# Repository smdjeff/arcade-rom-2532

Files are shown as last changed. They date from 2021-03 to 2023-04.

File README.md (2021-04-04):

# Vintage 2532 arcade ROM programmer for Raspberry Pi

* Most ROM programmers that support vintage ROMs require old PC hardware and interfaces like ISA, LPT ports that are no longer readily available.
* USB based programmers like the TL866 don't support the high voltages, long programming cycles and high currents required of vintage EEPROMs.

* Convenient Raspberry Pi Hat style form factor.
* Uses an eight bit shift register as both an IO expander and 5V level shifter to interface ROM address lines. 
* A real bi-directional level shifter for the ROM's data pins.
* An analog mux supporting the ROM's full high voltages and current.
* Simple C driver program used directly on the Pi's command line.
* [Smart single-byte retry algorithm](https://www.youtube.com/watch?v=HBokTF31uQM) accounts for difficult to program adddresses and lower VPP voltages.
* Supports several vintage classic arcade machine ROMs - like those in Space Invaders, Donkey Kong and Pacman.

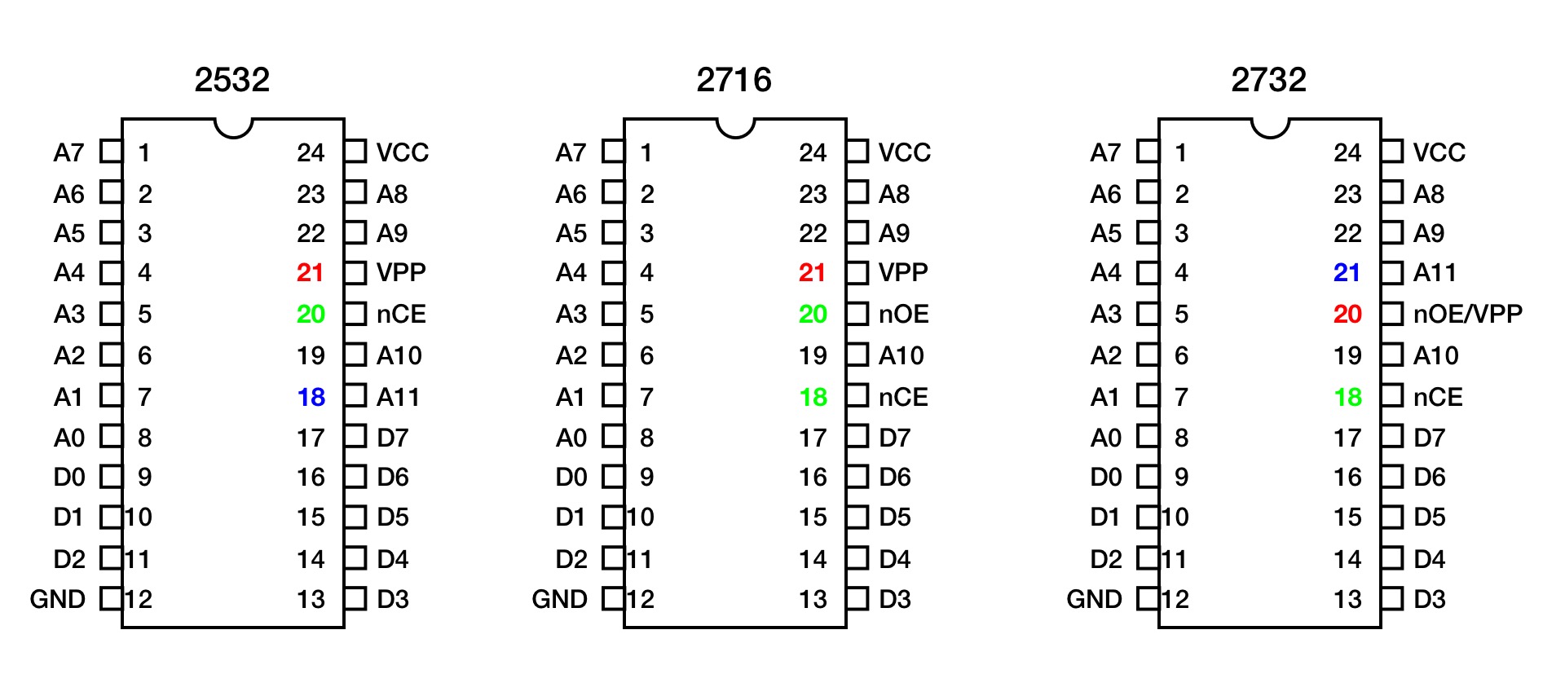
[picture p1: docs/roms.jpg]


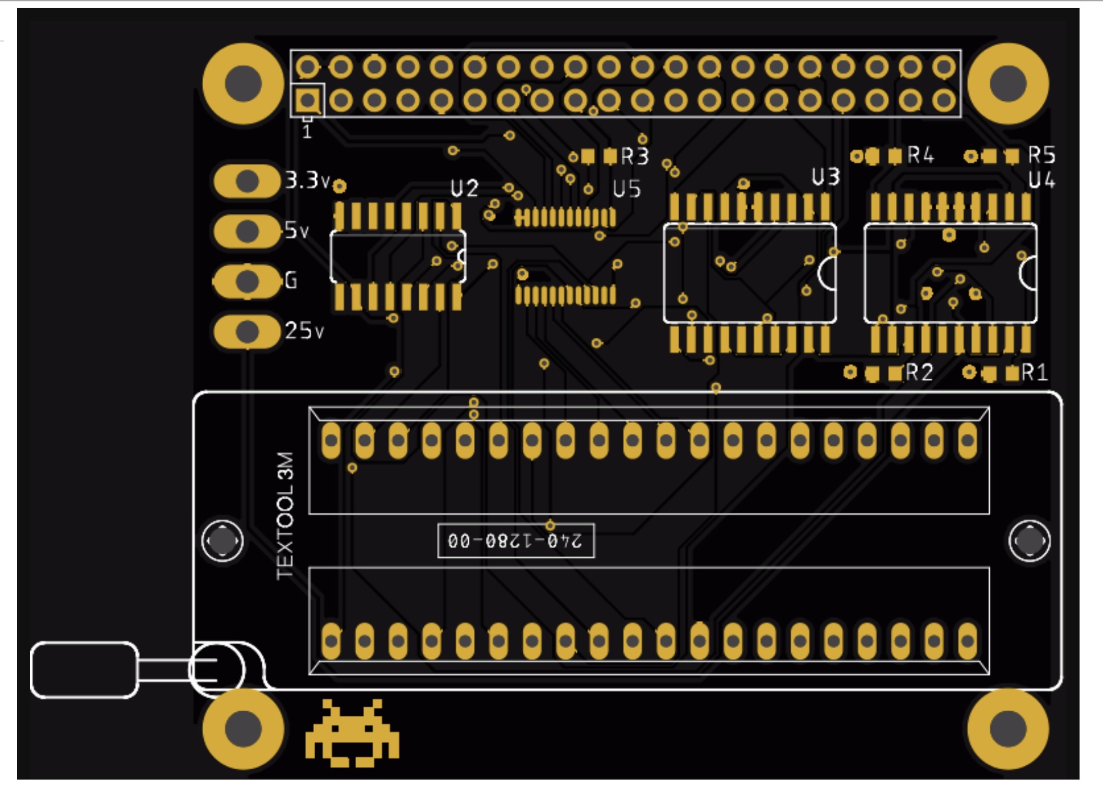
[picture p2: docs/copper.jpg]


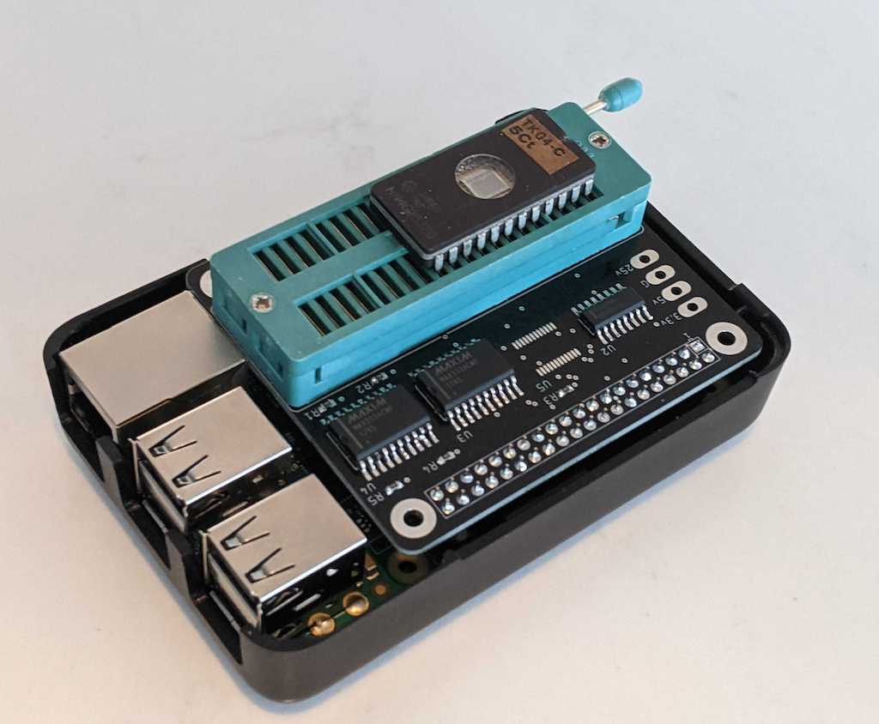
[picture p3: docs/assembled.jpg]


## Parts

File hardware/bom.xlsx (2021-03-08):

Designator | Manufacturer Part Number or Seeed SKU | Qty | Link
U1,U2 | MC74HCT595ADG | 2 | https://www.digikey.com/product-detail/en/MC74HCT595ADG/MC74HCT595ADGOS-ND/2748311/?itemSeq=357039637
U5 | SN74LVCC3245ADW | 1 | https://www.digikey.com/product-detail/en/SN74LVCC3245ADW/296-1704-5-ND/277350/?itemSeq=357039815
U3,U4 | MAX333ACWP+ | 2 | https://www.digikey.com/product-detail/en/MAX333ACWP%2b/MAX333ACWP%2b-ND/947930/?itemSeq=357039873
X2 | 2222 | 1 | https://www.digikey.com/product-detail/en/2222/1528-1785-ND/6238005/?itemSeq=357040007
R1,R2,R3,R4,R5 | CR0603-JW-103ELF | 5 | https://www.digikey.com/product-detail/en/CR0603-JW-103ELF/CR0603-JW-103ELFCT-ND/3592890/?itemSeq=357040105

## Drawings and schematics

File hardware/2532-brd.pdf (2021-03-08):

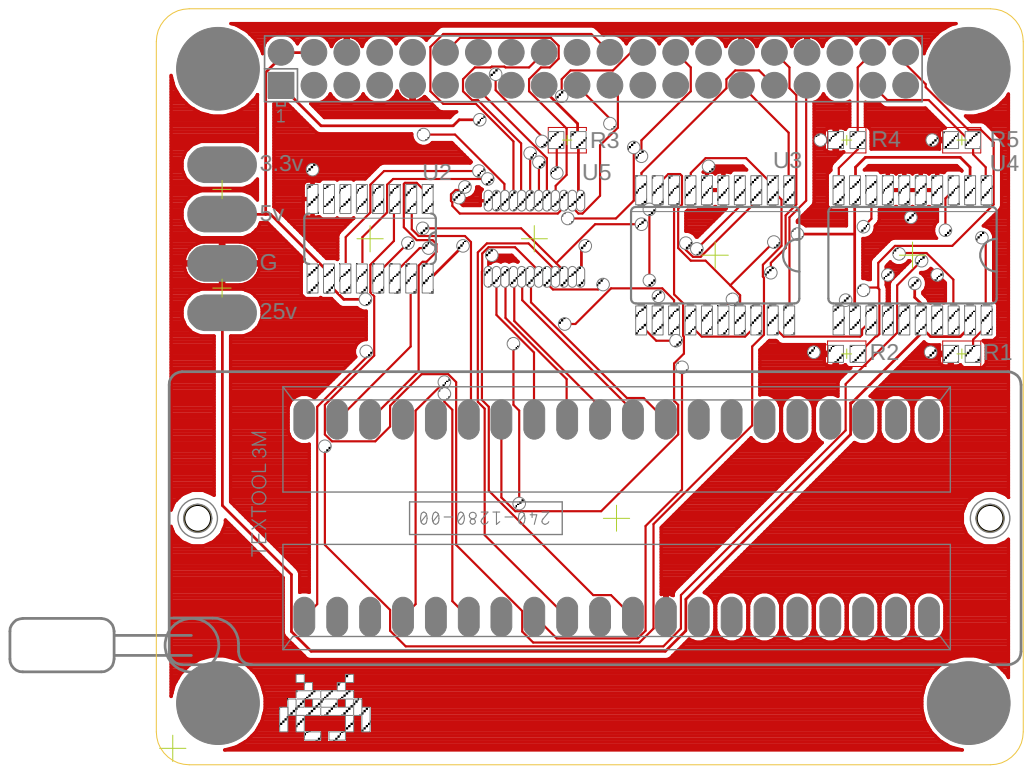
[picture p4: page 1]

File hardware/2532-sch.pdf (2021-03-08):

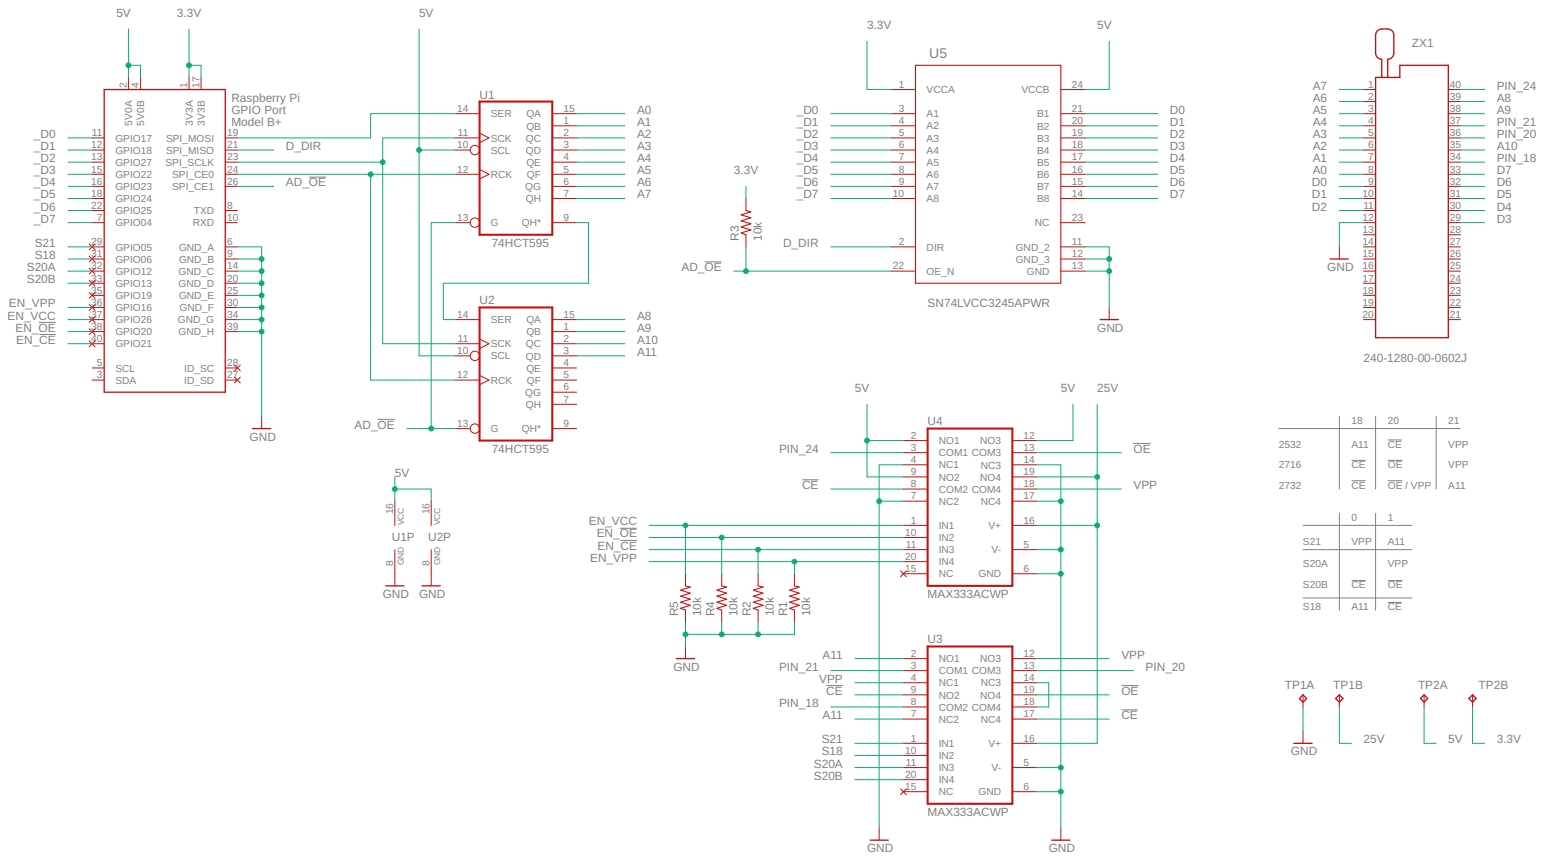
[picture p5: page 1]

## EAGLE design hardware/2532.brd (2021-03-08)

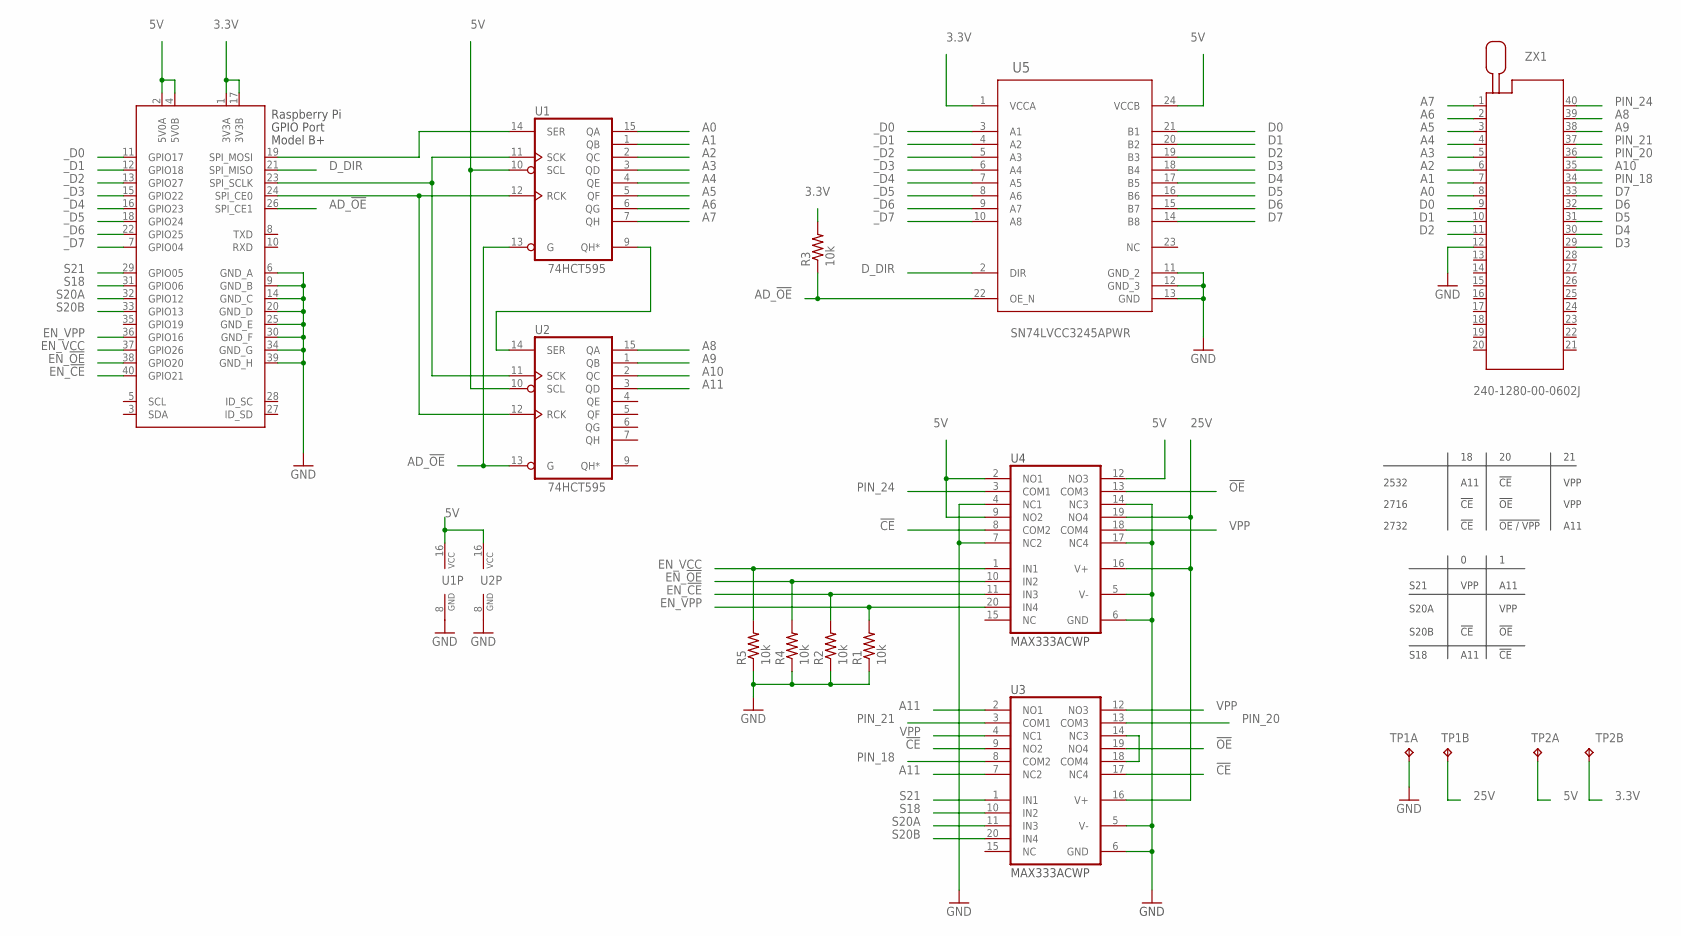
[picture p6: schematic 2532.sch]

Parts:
R1, R2, R3, R4, R5: 10k; R0603
TP1, TP2: TP2P2-38-17; P2-38-17
U1, U2: 74HCT595; SO16
U3, U4: MAX333ACWP; SO20L
U5: Value; PW0024A_N
X2: RASPI_BOARD_B+#_E4P; RASPI_BOARD_B+_EDGES_4DRILL_PAD
ZX1: 240-1280-00-0602J

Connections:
3.3V: R3.2, TP2.TP-2, U5.1 (VCCA), X2.1 (3V3A), X2.17 (3V3B)
5V: TP2.TP-1, U1.10 (SCL), U1.16 (VCC), U2.10 (SCL), U2.16 (VCC), U4.2 (NO1), U4.9 (NO2), U4.12 (NO3), U5.24 (VCCB), X2.2 (5V0A), X2.4 (5V0B)
25V: TP1.TP-2, U3.16 (V+), U4.16 (V+), U4.19 (NO4)
!CE: U3.9 (NO2), U3.17 (NC4), U4.8 (COM2)
!OE: U3.19 (NO4), U4.13 (COM3)
A0: U1.15 (QA), ZX1.8
A1: U1.1 (QB), ZX1.7
A2: U1.2 (QC), ZX1.6
A3: U1.3 (QD), ZX1.5
A4: U1.4 (QE), ZX1.4
A5: U1.5 (QF), ZX1.3
A6: U1.6 (QG), ZX1.2
A7: U1.7 (QH), ZX1.1
A8: U2.15 (QA), ZX1.39
A9: U2.1 (QB), ZX1.38
A10: U2.2 (QC), ZX1.35
A11: U2.3 (QD), U3.2 (NO1), U3.7 (NC2)
AD_!OE: R3.1, U1.13 (G), U2.13 (G), U5.22 (OE_N), X2.26 (SPI_CE1)
D0: U5.21 (B1), ZX1.9
D1: U5.20 (B2), ZX1.10
D2: U5.19 (B3), ZX1.11
D3: U5.18 (B4), ZX1.29
D4: U5.17 (B5), ZX1.30
D5: U5.16 (B6), ZX1.31
D6: U5.15 (B7), ZX1.32
D7: U5.14 (B8), ZX1.33
D_DIR: U5.2 (DIR), X2.21 (SPI_MISO)
EN_!CE: R2.2, U4.11 (IN3), X2.40 (GPIO21)
EN_!OE: R4.2, U4.10 (IN2), X2.38 (GPIO20)
EN_VCC: R5.2, U4.1 (IN1), X2.37 (GPIO26)
EN_VPP: R1.2, U4.20 (IN4), X2.36 (GPIO16)
GND: R1.1, R2.1, R4.1, R5.1, TP1.TP-1, U1.8 (GND), U2.8 (GND), U3.5 (V-), U3.6 (GND), U4.4 (NC1), U4.5 (V-), U4.6 (GND), U4.7 (NC2), U4.14 (NC3), U4.17 (NC4), U5.11 (GND_2), U5.12 (GND_3), U5.13 (GND), X2.6 (GND_A), X2.9 (GND_B), X2.14 (GND_C), X2.20 (GND_D), X2.25 (GND_E), X2.30 (GND_F), X2.34 (GND_G), X2.39 (GND_H), ZX1.12
unnamed: U3.14 (NC3), U3.18 (COM4)
unnamed: U1.11 (SCK), U2.11 (SCK), X2.23 (SPI_SCLK)
unnamed: U1.12 (RCK), U2.12 (RCK), X2.24 (SPI_CE0)
unnamed: U1.9 (QH*), U2.14 (SER)
unnamed: U1.14 (SER), X2.19 (SPI_MOSI)
PIN_18: U3.8 (COM2), ZX1.34
PIN_20: U3.13 (COM3), ZX1.36
PIN_21: U3.3 (COM1), ZX1.37
PIN_24: U4.3 (COM1), ZX1.40
S18: U3.10 (IN2), X2.31 (GPIO06)
S20A: U3.11 (IN3), X2.32 (GPIO12)
S20B: U3.20 (IN4), X2.33 (GPIO13)
S21: U3.1 (IN1), X2.29 (GPIO05)
VPP: U3.4 (NC1), U3.12 (NO3), U4.18 (COM4)
_D0: U5.3 (A1), X2.11 (GPIO17)
_D1: U5.4 (A2), X2.12 (GPIO18)
_D2: U5.5 (A3), X2.13 (GPIO27)
_D3: U5.6 (A4), X2.15 (GPIO22)
_D4: U5.7 (A5), X2.16 (GPIO23)
_D5: U5.8 (A6), X2.18 (GPIO24)
_D6: U5.9 (A7), X2.22 (GPIO25)
_D7: U5.10 (A8), X2.7 (GPIO04)

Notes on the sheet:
S21 S20A S20B S18
VPP !CE A11
A11 VPP !OE !CE
2532 2716 2732
!CE !OE !OE / VPP
VPP VPP A11
A11 !CE !CE

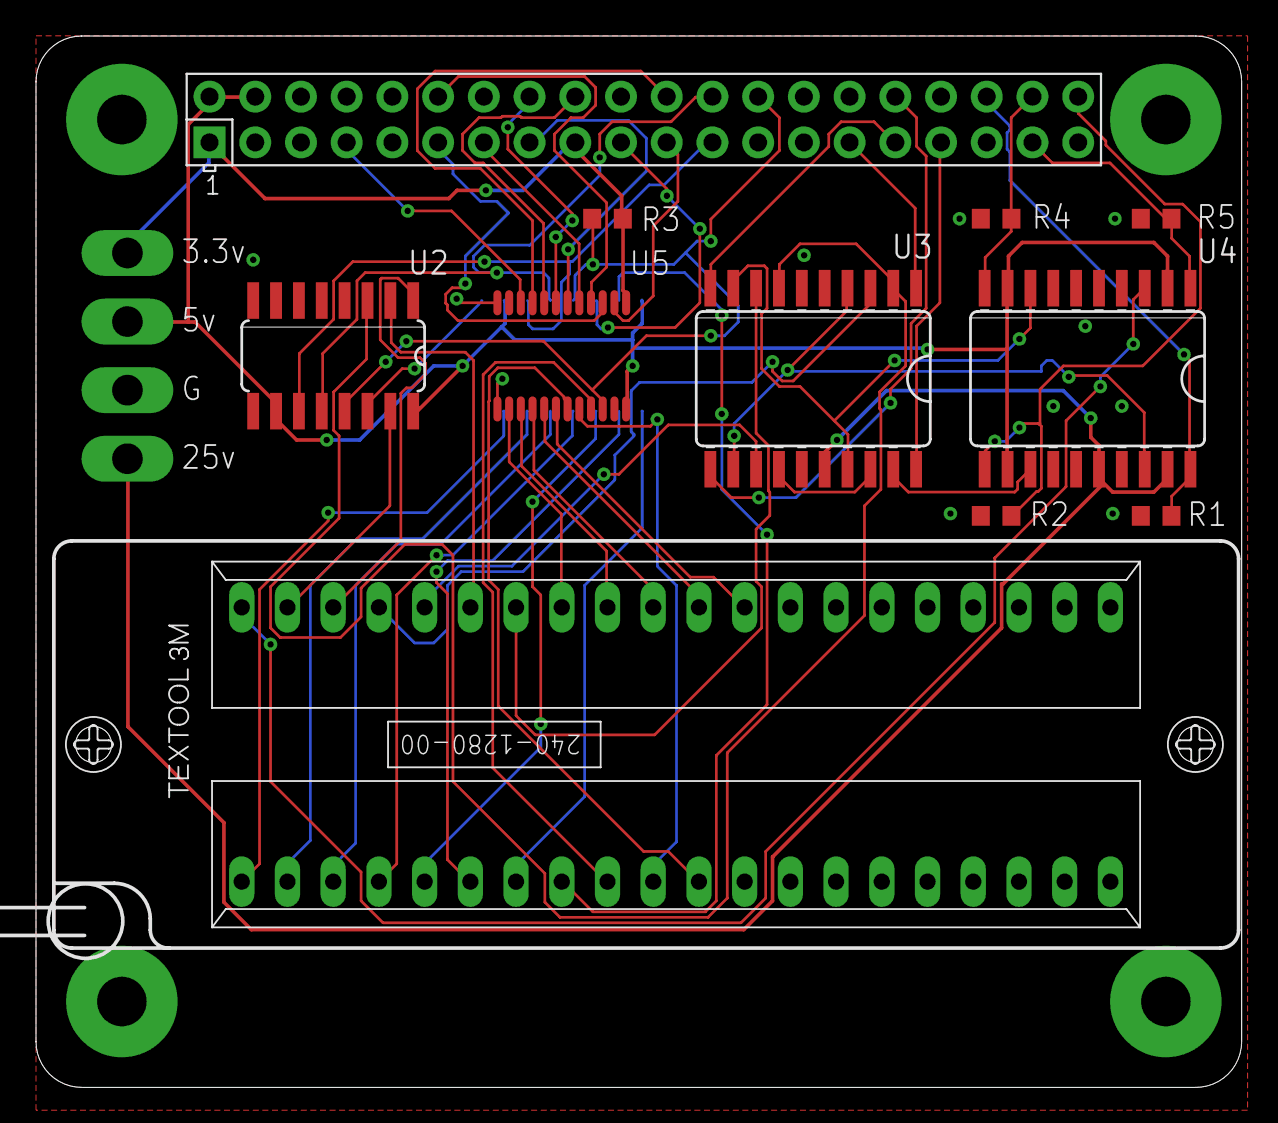
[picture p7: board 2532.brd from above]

Board: 2 copper layers, 67.0 x 58.4 mm, 14 parts (1 on the bottom side), 54 nets.

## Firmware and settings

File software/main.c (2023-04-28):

#define _GNU_SOURCE
#include <stdlib.h>
#include <stdint.h>
#include <stdbool.h>
#include <stdio.h>
#include <string.h>
#include <signal.h>
#include <sys/time.h>
#include <assert.h>
#include <unistd.h>

#include "portable.h"
#include "getchar_nonblock.h"

    
#define DELAY_US(us) do{ usleep(us); } while(0)    
#define DELAY_MS(ms) do{ usleep(ms*1000L); } while(0)

// note: do not connect 3.3V it is supplied via the Raspberry Pi
//       do not connect 5V it is supplied via Raspberry Pi's USB wallwart
//       VPP is supplied via external power supply
//       19-25vdc VPP for programming while higher voltages req fewer retries
//       at least 5.2vdc should be supplied to VPP during read/verify 
#define _5V         0
#define _25V        1

#define OFF         0
#define ON          1
#define LOW         0
#define HIGH        1

// hack: unfortunately the MAX333 analog switch is only good
// for up to 30mA and these older EPROMs need 160mA + on VCC
// so a PNP BJT is bluewired and that's inverting VCC logic  
#define VCC(v)      do { gpioWrite( EN_VCC, !v ); } while(0)

#define VPP(v)      do { gpioWrite( EN_VPP, v ); } while(0)
#define NCE(v)      do { gpioWrite( EN_NCE, v ); } while(0)
#define NPGM(v)     do { gpioWrite( EN_NCE, v ); } while(0)
#define NOE(v)      do { gpioWrite( EN_NOE, v ); } while(0)


typedef enum {
    rom2532,
    rom2716,
    rom2732
} romType_t;


static void romSelect(romType_t romType) {
    switch (romType) {
        case rom2532:
            printf("2532 selected\n");
            // all pins check out
            gpioWrite( IO_S18,  0 ); // pin 18  [0:A11] 1:nCE
            gpioWrite( IO_S20A, 0 ); // pin 20  [0:20B] 1:VPP
            gpioWrite( IO_S20B, 0 ); //         [0:nCE] 1:nOE
            gpioWrite( IO_S21,  0 ); // pin 21  [0:VPP] 1:A11
            break;
        case rom2716:
            printf("2716 selected\n");
            gpioWrite( IO_S18,  1 ); // pin 18  0:A11 [1:nCE]
            gpioWrite( IO_S20A, 0 ); // pin 20  [0:20B] 1:VPP
            gpioWrite( IO_S20B, 1 ); //         0:nCE [1:nOE]
            gpioWrite( IO_S21,  0 ); // pin 21  [0:VPP] 1:A11
            break;
        case rom2732:
            printf("2732 selected\n");
            printf("warning: support for this chip is incomplete\n"); getchar();
            // A11 bad, & nCE/nOE issue?
            gpioWrite( IO_S18,  1 ); // pin 18  0:A11 [1:nCE]
            gpioWrite( IO_S20A, 1 ); // pin 20  0:20B [1:VPP]
            gpioWrite( IO_S20B, 1 ); //         0:nCE [1:nOE]
            gpioWrite( IO_S21,  1 ); // pin 21  0:VPP [1:A11]
            break;
        default:
            assert(false);
            break;
    }
}


static void dataPinsMode(int mode) {
    uint8_t pins[] = { 
        IO_D0, IO_D1, IO_D2, IO_D3, IO_D4, IO_D5, IO_D6, IO_D7
    };
    for (int i=0; i<sizeof(pins); i++) {
        gpioWrite( pins[i], 0 );
        gpioSetMode( pins[i], mode );
    }
    // SN74LVCC3245 mode
    if ( mode == PI_OUTPUT ) {        
        gpioWrite( D_DIR, 1 ); // A data to B bus
    } else {
        gpioWrite( D_DIR, 0 ); // B data to A bus
    }
}


static void controlPinsMode(int mode) {
    typedef struct {
        int gpio;
        int value;
    } pins_t;
    pins_t pins[] = { 
        {IO_S21,0}, {IO_S18,0}, {IO_S20A,0}, {IO_S20B,0},
        {EN_VPP,0}, {EN_VCC,0}, {EN_NOE,1}, {EN_NCE,1},
        {D_DIR,0}, {AD_NOE,0},
        {SPI_CE0,1}, {SPI_MOSI,0}, {SPI_CLK,0}
    };
    for (int i=0; i<sizeof(pins)/sizeof(pins[0]); i++) {
        printf("gpio %d value:%d mode:%d\n", pins[i].gpio, pins[i].value, mode );
        gpioWrite( pins[i].gpio, pins[i].value );
        gpioSetMode( pins[i].gpio, mode );
    }
}


static void writeAddress(uint16_t addr) {
    // put the address out on the MC74HCT595
    gpioWrite( SPI_CE0, 0 );
    for (int i=15; i>=0; i--) {  // msb
        gpioWrite( SPI_CLK, 0 );
        DELAY_US(1);
        gpioWrite( SPI_MOSI, (addr & (1<<i) ? 1:0) );
        DELAY_US(1);
        gpioWrite( SPI_CLK, 1 ); // shift bit in
        DELAY_US(1);
    }
    gpioWrite( SPI_CE0, 1 );  // latch 595
    gpioWrite( SPI_CLK, 0 );
    gpioWrite( SPI_MOSI, 0 );
}


static void writeByte(uint8_t b) {
    // put the data out on the SN74LVCC3245
    dataPinsMode( PI_OUTPUT );
    gpioWrite( IO_D0, (b & 0b00000001)?1:0 );
    gpioWrite( IO_D1, (b & 0b00000010)?1:0 );
    gpioWrite( IO_D2, (b & 0b00000100)?1:0 );
    gpioWrite( IO_D3, (b & 0b00001000)?1:0 );
    gpioWrite( IO_D4, (b & 0b00010000)?1:0 );
    gpioWrite( IO_D5, (b & 0b00100000)?1:0 );
    gpioWrite( IO_D6, (b & 0b01000000)?1:0 );
    gpioWrite( IO_D7, (b & 0b10000000)?1:0 );
}


static void readByte(uint8_t *b) {
    // read data in from the SN74LVCC3245
    dataPinsMode( PI_INPUT );
    *b =  gpioRead( IO_D0 );
    *b |= gpioRead( IO_D1 ) << 1;
    *b |= gpioRead( IO_D2 ) << 2;
    *b |= gpioRead( IO_D3 ) << 3;
    *b |= gpioRead( IO_D4 ) << 4;
    *b |= gpioRead( IO_D5 ) << 5;
    *b |= gpioRead( IO_D6 ) << 6;
    *b |= gpioRead( IO_D7 ) << 7;
}


// Intel 2716
static void write2716(uint8_t *data, int sz) {
    // VPP always at +25V
    // for each byte, Pull \OE high, delay 1 usec
    // assert address, assert data, delay 2 usec
    // pulse \CE high for 55msec
    // set data as inputs
    // pull \OE low, wait 1usec
    // verify correct data being asserted by target.

    NCE( LOW );
    NOE( LOW );
    VPP( _25V );
    DELAY_US( 2 );

    for (int i=0; i<sz; i++ ) {
      uint8_t w = data[i];
      uint8_t r = 0xff;

      for (int j=0; j<10; j++ ) {

        NOE( HIGH );
        DELAY_US( 1 );

        writeAddress( i );
        writeByte( w );
        DELAY_US( 2 );

        NCE( HIGH );
        DELAY_MS( 55 );
        NCE( LOW );

        dataPinsMode( PI_INPUT );

        DELAY_US( 2 );
        NOE( LOW );
        DELAY_US( 1 );

        readByte( &r );
        if ( r == w ) {
           break;
        } else {
           printf("RETRY addr:%04x wrote:%02x read:%02x\n",i, w, r );
   	   DELAY_MS( 250 );
        }
      }

      printf("%saddr:%04x wrote:%02x read:%02x\n",(r==w)?"":"*FAIL* ",i, w, r );
    }

    VPP( _5V );
}

static void write2732(uint8_t *data, int sz) {
/*
2732 is: Start with \CE high, \OE low.  Raise \OE to VPP, delay 1usec, assert address, assert data, delay 2 usec, pulse \CE low for 55msec, delay 2 usec, pull \OE low, delay 2 usec, pull \CE low, delay 1 usec, verify correct data being asserted by target.
*/
    
    NCE( HIGH );
    NOE( LOW );

    VPP( _25V );
    DELAY_US( 1 );
    
    for (int i=0; i<sz; i++ ) {
        // //*** OE/CE?
        uint8_t w = data[i];
        writeAddress( i );
        writeByte( w );
        DELAY_US( 2 );

        NCE( LOW );  //*** opposite of 2716?
        DELAY_MS( 55 );
        NCE( HIGH );  //***
        DELAY_US( 2 );
        
        NOE( LOW ); 
        DELAY_US( 2 );
        NCE( LOW ); 
        DELAY_US( 1 );
        
        uint8_t r = 0xff;
        readByte( &r );
        if ( r != w ) {
            printf("FAIL ");
        }
        printf("addr:%04x wrote:%02x read:%02x\n", i, w, r );
    }
    
    VPP( _5V );
}


// Texas Instruments TMS2532
static void writeTMS2532(uint8_t *data, int sz) {
/*
-With \PGM high, assert address
-Raise Vpp from VCC to +25V
-Assert data
-Wait at least 2 microseconds
-Pulse \PGM low for 55 milliseconds
*/
    NPGM( HIGH );
    DELAY_US( 2 );

    for (int i=0; i<sz; i++ ) {
        uint8_t w = data[i];

        writeAddress( i );
        
        VPP( _25V );
        DELAY_US( 2 );

        writeByte( w );
        DELAY_US( 2 );

        NPGM( LOW ); 
        DELAY_MS( 55 );
        NPGM( HIGH );
        DELAY_US( 2 );
        
        VPP( _5V );
        
        uint8_t r = 0xff;
        readByte( &r );
        if ( r != w ) {
            printf("FAIL ");
        }
        printf("addr:%04x wrote:%02x read:%02x\n", i, w, r );
    }
}

// Hitachi HD462532
static void writeHD2532(uint8_t *data, int sz) {
    // Start with \CE high
    // raise VPP to +25V
    // assert address
    // assert data
    // delay 2usec
    // pulse \CE low for 55msec
    // delay 2usec
    // lower VPP to +5V, 
    // delay 2usec
    // pull \CE low
    // verify correct data being asserted by target
    
    for (int i=0; i<sz; i++ ) {
      uint8_t w = data[i];
      uint8_t r = 0xff;
      
      for (int j=0; j<10; j++ ) {

        NCE( LOW ); 
        writeAddress( i );
//        readByte( &r );
//        if ( r == w ) { break; } 

        NCE( HIGH );
        VPP( _25V );

        writeByte( w );
        DELAY_US( 2 );
        
        NCE( LOW ); 
        DELAY_MS( 55 );
        NCE( HIGH ); 
        DELAY_US( 2 );

        VPP( _5V );
        DELAY_US( 2 );
        
        NCE( LOW );  
        DELAY_US( 1 );
        
        readByte( &r );
        if ( r == w ) {
           break;
        } else {
           fprintf(stderr,"RETRY addr:%04x wrote:%02x read:%02x\n",i, w, r );
   	   DELAY_MS( 1000 );
        }
      }
      printf("%saddr:%04x wrote:%02x read:%02x\n",(r==w)?"":"*FAIL* ",i, w, r );
    } 
}


static void romRead(uint8_t *data, int sz) {
    dataPinsMode( PI_INPUT );
    
    NOE( LOW );
    NCE( LOW );

    for (int i=0; i<sz; i++ ) {
        writeAddress( i );
        readByte( &data[i] );
    }
}


int main(int argc, char *argv[]) {

    if (argc < 4) {
       printf("Usage:\n romhat [TMS2532|HD2532|2716|2732] -w|r|v|b file\n");
       exit(1);
    }
    char *type = argv[1];
    char *mode = argv[2];
    char *filename = argv[3];

    assert( gpioInitialise() >= 0 );
    controlPinsMode( PI_OUTPUT );
    dataPinsMode( PI_INPUT );
    gpioWrite( AD_NOE,  0 ); // enables outputs of 595 and 245
    
    printf("VCC ON\n"); 
    VCC( ON );

    int romSize = 0;
    void (*romWrite)(uint8_t *data, int sz) = NULL;

    if ( strcasestr( type, "HD2532" ) ) {
        romSize = 32 *1024/8;            
        romSelect( rom2532 );
        romWrite = writeHD2532;
    }
    else if ( strcasestr( type, "TMS2532" ) ) {
        romSize = 32 *1024/8;            
        romSelect( rom2532 );
        romWrite = writeTMS2532;
    }
    else if ( strcasestr( type, "2716" ) ) {
        romSize = 16 *1024/8;            
        romSelect( rom2716 );
        romWrite = write2716;
    }
    else if ( strcasestr( type, "2732" ) ) {
        romSize = 32 *1024/8;            
        romSelect( rom2732 );
        romWrite = write2732;
    } 

    printf("rom type selection complete\n"); 

    if ( strcasestr( mode, "t" ) ) {
        printf("pin test\n"); getchar();

        int gpio[] = { 0,2,3,4,0,17,27,22,0,10,9,11,0,0,5,6,13,19,26,0 };
	for (int i=0; i<sizeof(gpio)/sizeof(gpio[0]); i++) {
           if ( gpio[i] == 0 ) {
              printf("pin:%d skip\n", 1+(i*2));
              continue;
           }
           printf("pin:%d gpio: %d\n", 1+(i*2), gpio[i]);
	   gpioSetMode( gpio[i], PI_OUTPUT );
           nonblocking( true );
           do {
              DELAY_MS( 500 );
              int v = !gpioRead( gpio[i] );
  	      gpioWrite( gpio[i], v );
           } while ( getchar_nonblock()==0 );
           nonblocking( false );
        }

	controlPinsMode( PI_OUTPUT ); getchar();
	controlPinsMode( PI_INPUT ); getchar();

	controlPinsMode( PI_OUTPUT );
        for (int i=0; i<12; i++) {
            writeAddress( 1<<i );
            printf("A%d HI\n",i); getchar();
        }

	dataPinsMode( PI_OUTPUT ); getchar();
	dataPinsMode( PI_INPUT ); getchar();

	dataPinsMode( PI_OUTPUT );
        for (int i=0; i<8; i++) {
            writeByte( 1<<i );
            printf("D%d HI\n",i); getchar();
        }
	dataPinsMode( PI_INPUT );

        printf("VPP ON\n"); VPP( ON ); getchar();
        printf("VPP OFF\n"); VPP( OFF );getchar();
    
        printf("NCE HIGH\n"); NCE( HIGH ); getchar();
        printf("NCE LOW\n"); NCE( LOW ); getchar();

        printf("NOE HIGH\n"); NOE( HIGH ); getchar();
        printf("NOE LOW\n"); NOE( LOW ); getchar();
    }

    if ( strcasestr( mode, "w" ) ) {
        printf("write\n");

        if( access( filename, F_OK ) == 0 ) {
            char *data = malloc( romSize );
            assert( data );
            FILE *fp = fopen( filename, "rb" );
            fread( data, 1, romSize, fp );
            fclose( fp );
            romWrite( data, romSize );
            free( data );

        } else {
            printf("file %s doesn't exist\n", filename);
        }
    }

    if ( strcasestr( mode, "r" ) ) {
        printf("reading...\n");

        char *data = malloc( romSize );
        assert( data );
        romRead( data, romSize );
        FILE *fp = fopen( filename, "wb" );
        fwrite( data, 1, romSize, fp );
        fclose( fp );
        for (int i=0; i<romSize; i++ ) {
            printf("addr:%04x read:%02x\n", i, data[i] );
        }
        free( data );
    }  

    if ( strcasestr( mode, "v" ) ) {
        printf("verifying...\n");

        char *data = malloc( romSize );
        assert( data );
        romRead( data, romSize );

        char *datafile = malloc( romSize );
        assert( datafile );
        FILE *fp = fopen( filename, "rb" );
        fread( datafile, 1, romSize, fp );

        int fail = 0;
        for (int i=0; i<romSize; i++) {
            printf("addr:%04x file:%02x read:%02x", i, datafile[i], data[i]);
            if ( data[i] != datafile[i] ) {
                fail++;
                printf(" FAIL\n");
                sleep(1);
	    }
            printf("\n");
        }

        free( datafile );
        free( data );
        if ( fail == 0 ) {
           printf("PASS\n");
	} else {
           printf("FAILED %d of %d bytes\n", fail, romSize); 
        }
    }  

    if ( strcasestr( mode, "b" ) ) {
        printf("blank checking...\n");

        char *data = malloc( romSize );
        assert( data );
        romRead( data, romSize );

        int fail = 0;
        for (int i=0; i<romSize; i++) {
            printf("addr:%04x read:%02x", i, data[i]);
            if ( data[i] != 0xff ) {
                fail++;
                printf(" FAIL\n");
                sleep(1);
            }
            printf("\n");
        }
        free( data );
        if ( fail == 0 ) {
            printf("BLANK\n");
        } else {
            printf("FAILED %d of %d bytes\n", fail, romSize);
        }
    }
        
    printf("VCC OFF\n"); 
    VCC( OFF );

    gpioWrite( AD_NOE,  1 ); // disables outputs of 595 and 245
    dataPinsMode( PI_INPUT );
//    controlPinsMode( PI_INPUT );
    gpioTerminate();
    return 0;
}

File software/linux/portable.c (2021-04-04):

#include <stdlib.h>
#include <stdint.h>
#include <stdio.h>
#include <string.h>
#include <sys/time.h>
#include <unistd.h>

#include "portable.h"


int gpioInitialise(void) { 
    printf("gpioInitialise\n");
    sleep(1);
    return 0;
}

void gpioTerminate(void) {
    printf("gpioTerminate\n");
    sleep(1);
}

int gpioSetMode(unsigned gpio, unsigned mode) { 
    printf("gpio[%d] %s\n", gpio, (mode?"input":"output"));
    return 0; 
}

int gpioSetTimerFunc(unsigned timer, unsigned millis, gpioTimerFunc_t f) {
    return 0; 
}

int gpioSetAlertFunc(unsigned user_gpio, gpioAlertFunc_t f) {
    return 0; 
}

pthread_t *gpioStartThread(gpioThreadFunc_t f, void *userdata) {
    return 0;
}

static int gpioState[41] = {0,};

int gpioWrite(unsigned gpio, unsigned level) {
    printf("gpio[%d] wr %d\n", gpio, level);
//    sleep(1);
    gpioState[gpio] = level;
    return 0; 
}

int gpioRead(unsigned gpio) { 
    int level = gpioState[gpio];
    printf("gpio[%d] rd %d\n", gpio, level);
//    sleep(1);
    return level;
}

int gpioSetPullUpDown(unsigned gpio, unsigned pud) { 
    return 0; 
}

int gpioPWM(unsigned user_gpio, unsigned dutycycle) { 
    return 0; 
}

int gpioSetPWMfrequency(unsigned gpio, unsigned frequency) {
    return 0;
}

int gpioGetPWMfrequency(unsigned gpio) {
    return 0;
}

int gpioCfgClock(unsigned micros, unsigned peripheral, unsigned source) {
    return 0;
}

int gpioGlitchFilter(unsigned user_gpio, unsigned steady) {
    return 0;
}

int i2cWriteByteData(unsigned handle, unsigned i2cReg, unsigned bVal) {
    return 0; 
}

int i2cOpen(unsigned i2cBus, unsigned i2cAddr, unsigned i2cFlags) { 
    return 0; 
}
